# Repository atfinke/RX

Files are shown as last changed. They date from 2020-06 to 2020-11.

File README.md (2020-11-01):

# RX

A small stay at home side project. Bluetooth buttons that trigger actions on a Mac.
<br> <br><p align="center">
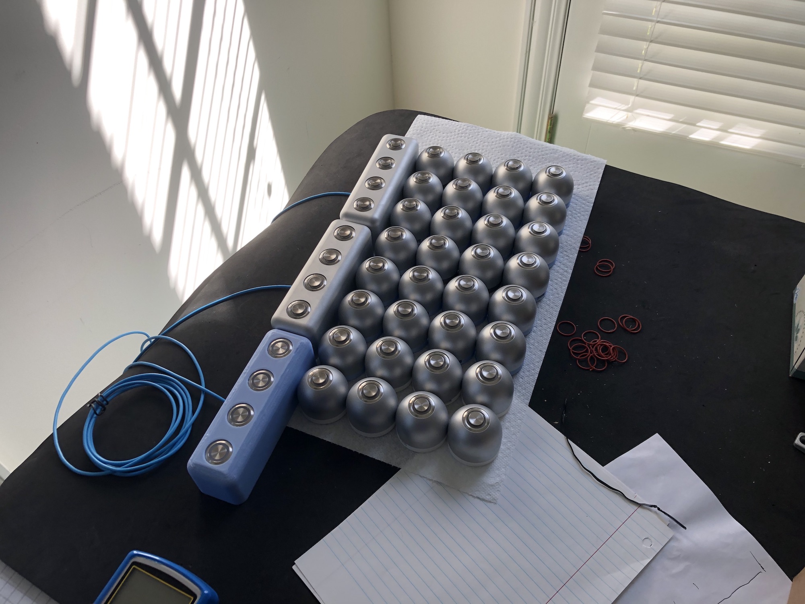
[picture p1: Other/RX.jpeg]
  
</p>

- R1 = V1: Bluetooth, USB Power
- R2 = V2: Bluetooth, Battery + Wireless Charging
- RM = Control theatre volume via Apple TV. Lights up when shaken to find in the dark.
- RD = Single button remote

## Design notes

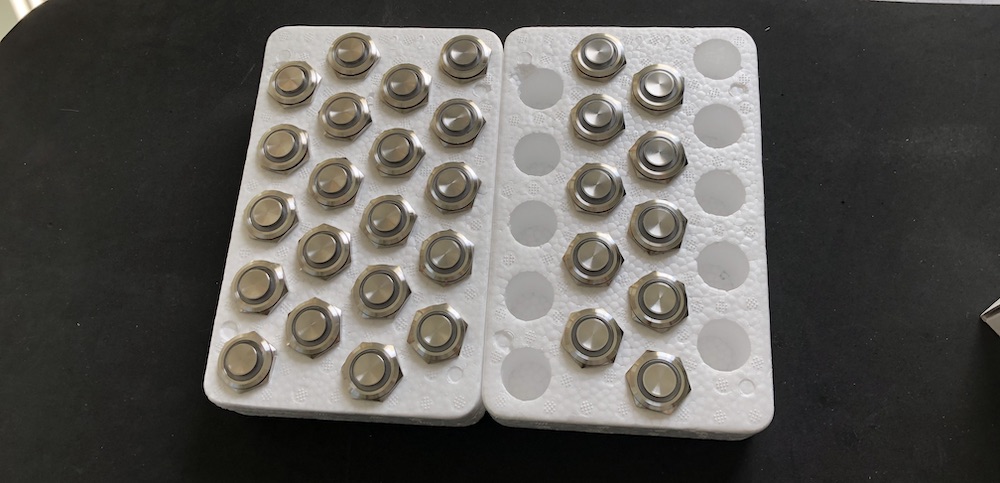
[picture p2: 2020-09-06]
RD/images/RD Buttons.jpg

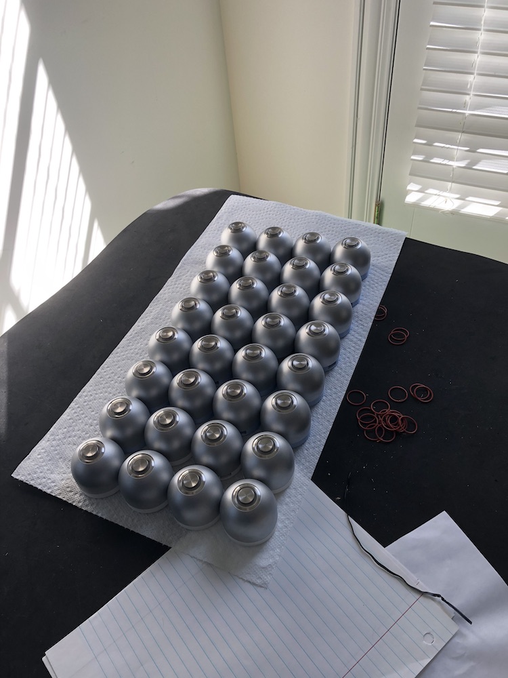
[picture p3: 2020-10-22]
RD/images/RD Complete.jpeg

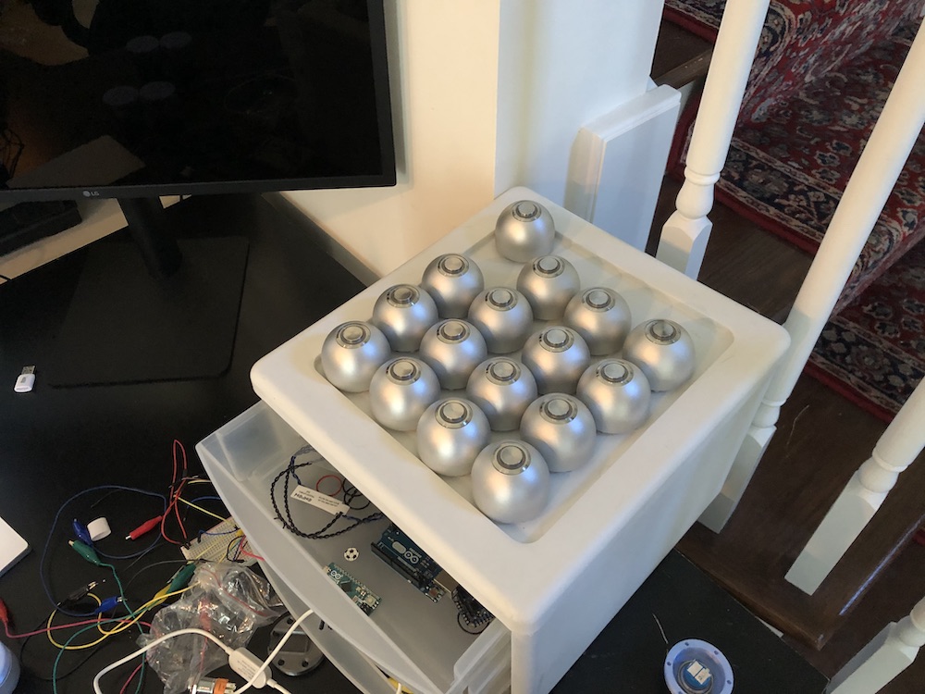
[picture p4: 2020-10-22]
RD/images/RD Without Base.jpeg

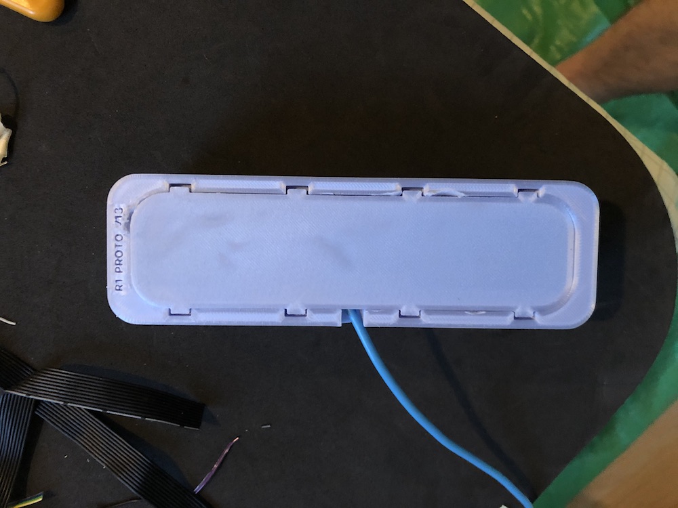
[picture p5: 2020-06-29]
R1/images/Proto V13 Bottom.jpeg

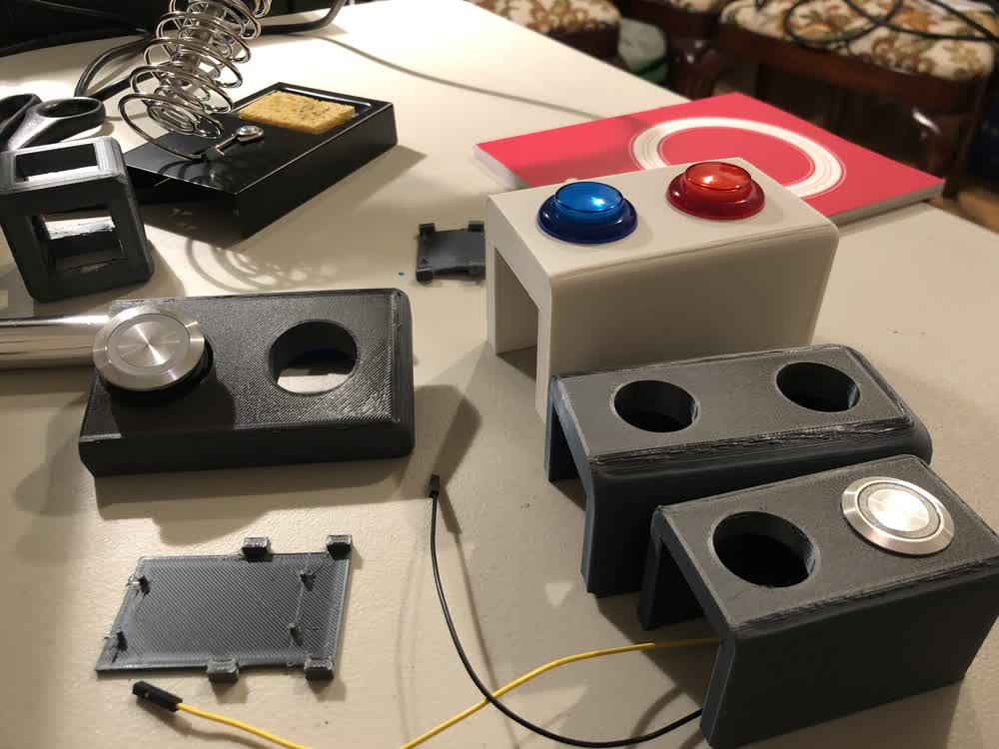
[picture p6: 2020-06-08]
R1/images/Proto V0 - V3.jpeg

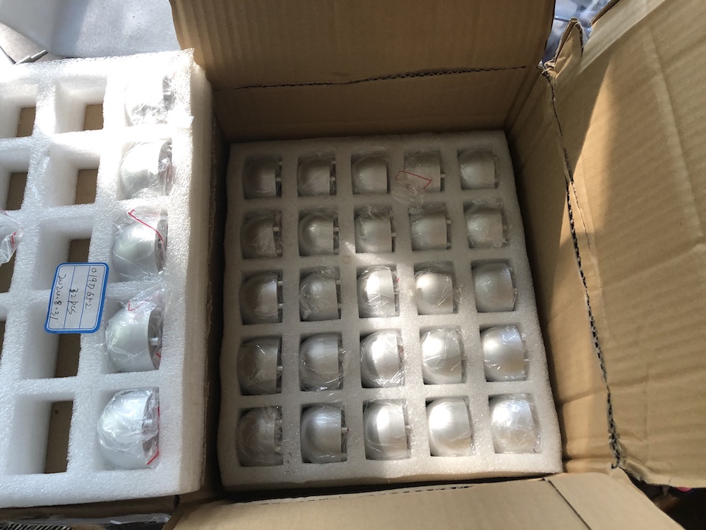
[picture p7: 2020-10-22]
RD/images/RD Enclosures.jpeg

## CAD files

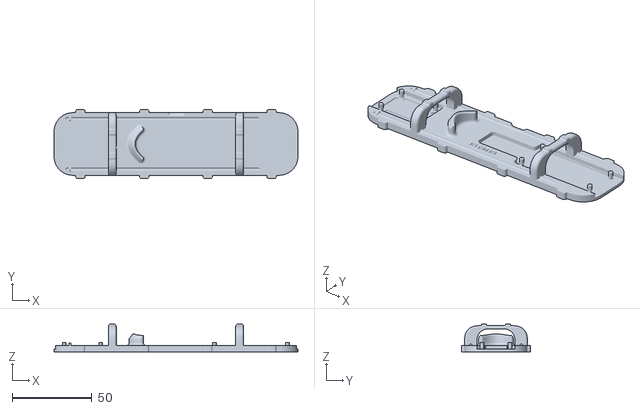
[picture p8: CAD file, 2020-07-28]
R1/cad/R1 RC B1.stl
153.2 x 43.4 x 17.4

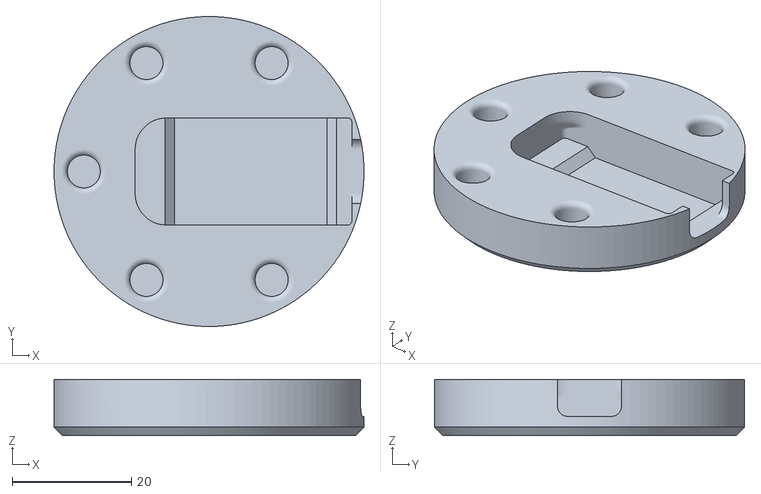
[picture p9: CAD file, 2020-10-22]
RD/cad/RD V17 B.stl
52.0 x 52.0 x 9.40

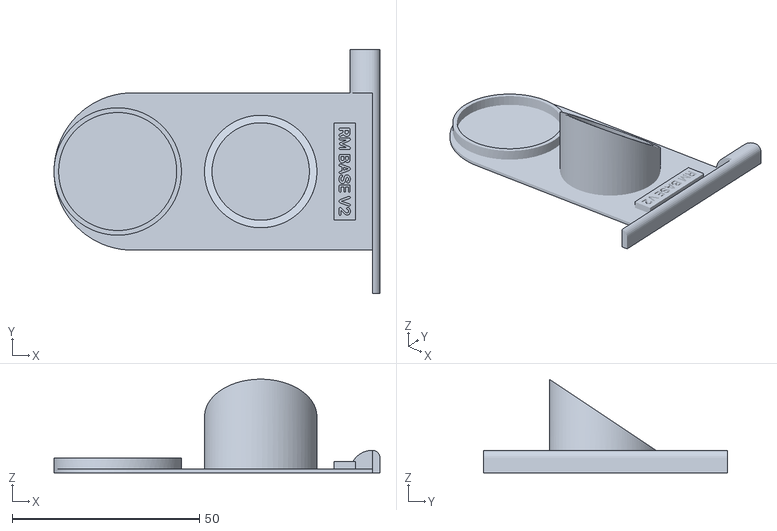
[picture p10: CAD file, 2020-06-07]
RM/cad/RM Base V2.stl
87.0 x 65.0 x 25.0

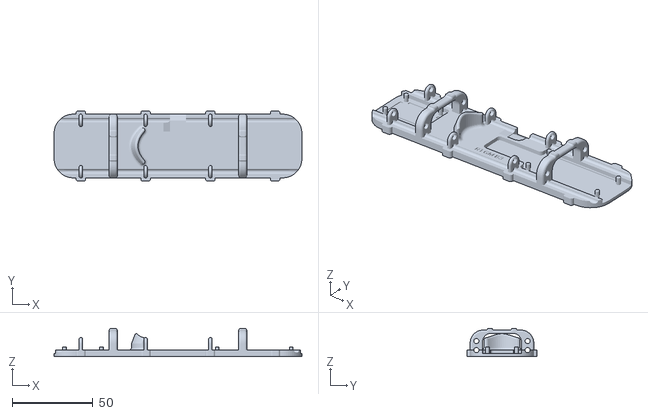
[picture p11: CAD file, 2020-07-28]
R1/cad/R1 RC B3.stl
153.2 x 43.4 x 17.4

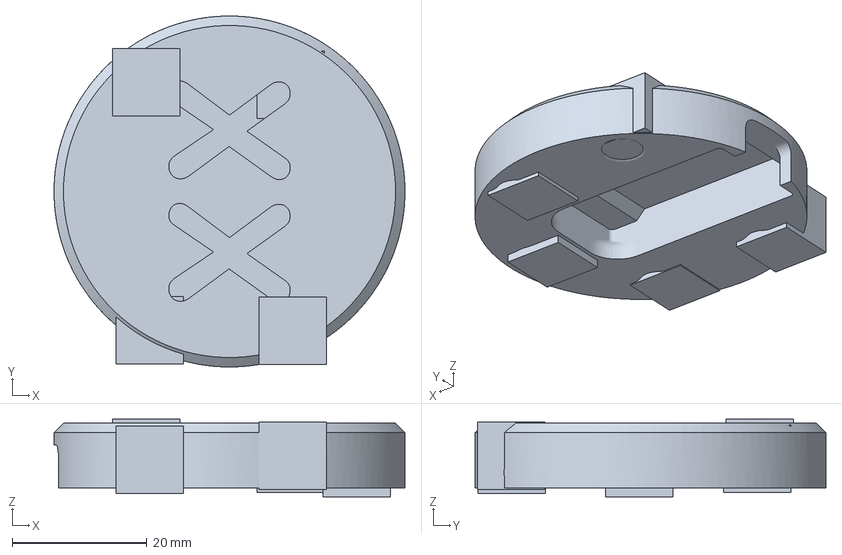
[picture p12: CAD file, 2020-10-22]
RD/cad/Cura Proj RD RC B.3mf
52.0 x 52.0 x 11.5 mm

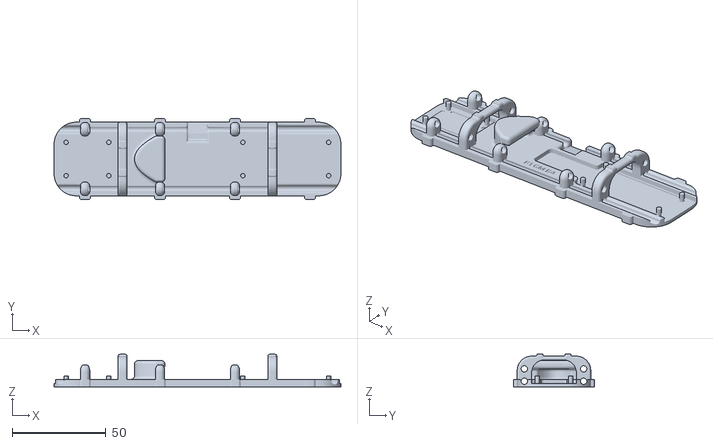
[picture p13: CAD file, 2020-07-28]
R1/cad/R1 RC B4.stl
153.2 x 43.4 x 17.4

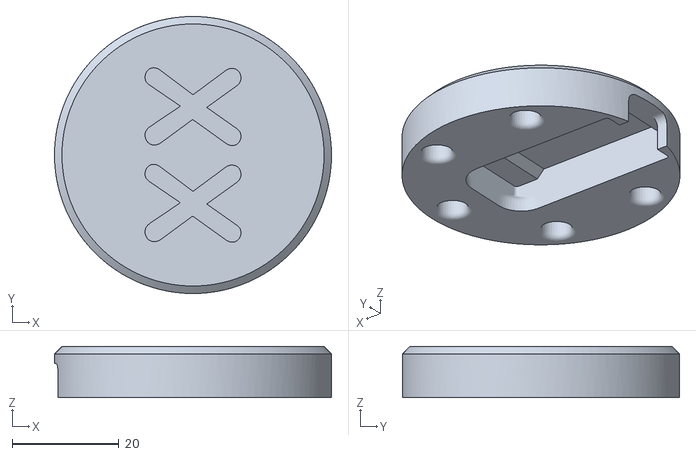
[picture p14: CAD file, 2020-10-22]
RD/cad/RD RC B.stl
52.0 x 52.0 x 9.60

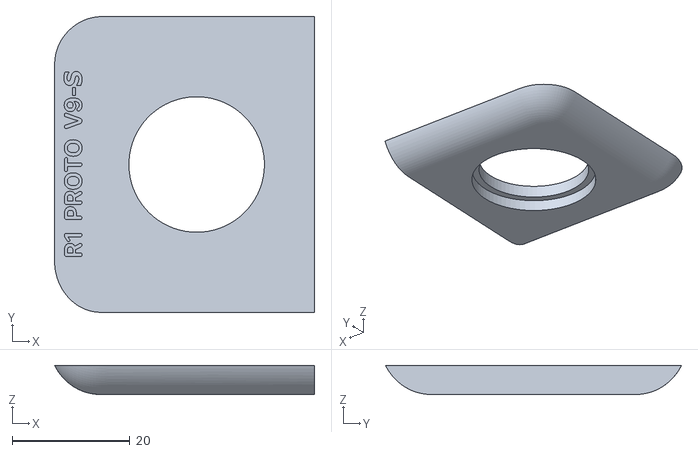
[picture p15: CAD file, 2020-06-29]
R1/cad/R1 Proto V9 - Fruit - No Support Test.stl
44.1 x 50.3 x 5.00

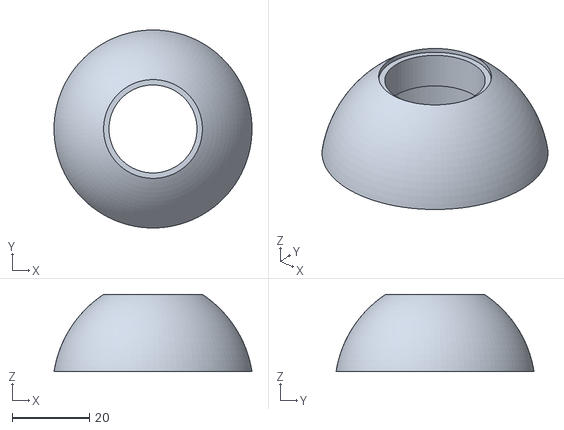
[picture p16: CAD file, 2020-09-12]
RD/cad/RD V8 T2.stl
51.3 x 51.3 x 20.0

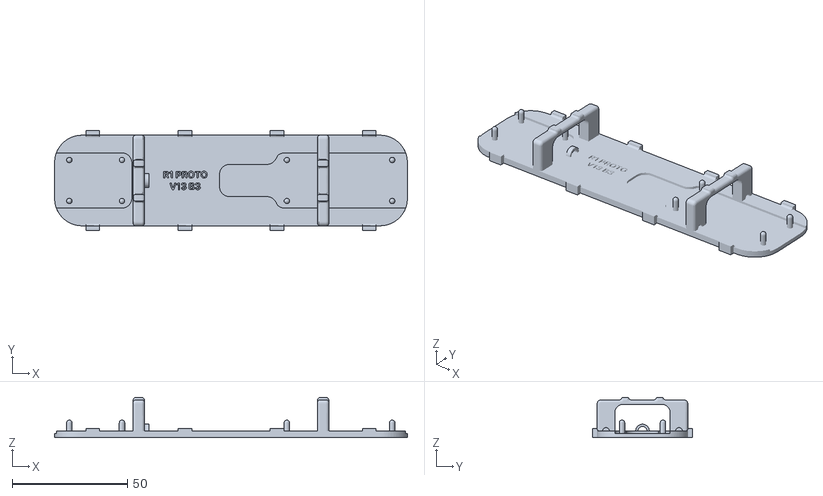
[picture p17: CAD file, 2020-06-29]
R1/cad/R1 Proto V13 B3.stl
153.2 x 43.4 x 17.4

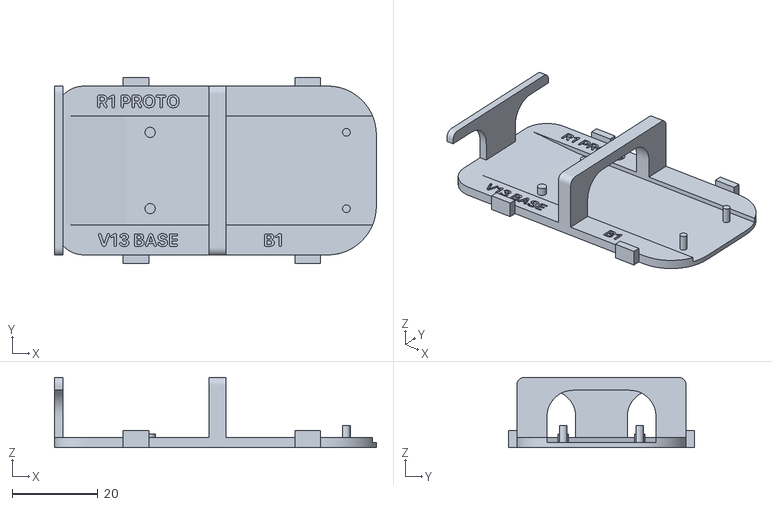
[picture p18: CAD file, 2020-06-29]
R1/cad/R1 Proto V13 B1.stl
75.0 x 43.4 x 16.4

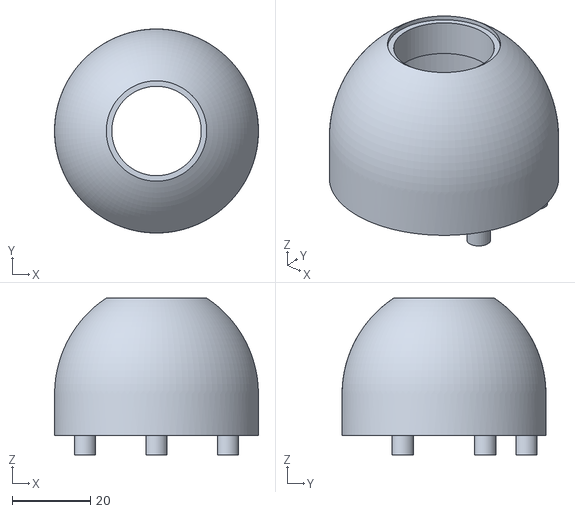
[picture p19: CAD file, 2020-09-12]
RD/cad/RD RC T.stl
52.0 x 52.0 x 40.0

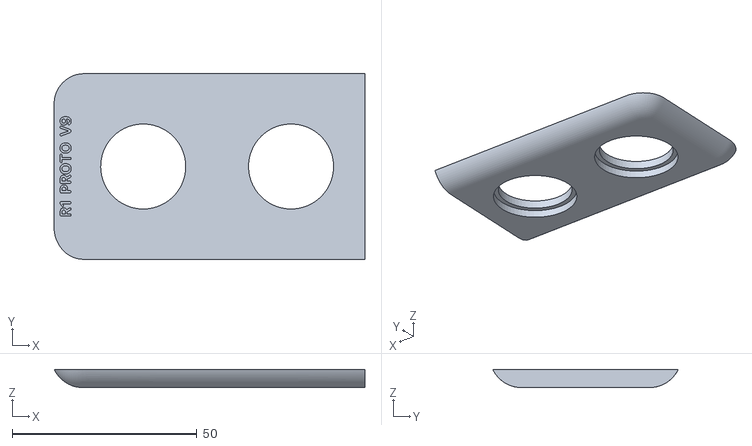
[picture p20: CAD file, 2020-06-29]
R1/cad/R1 Proto V9 - Fruit.stl
84.1 x 50.3 x 5.00

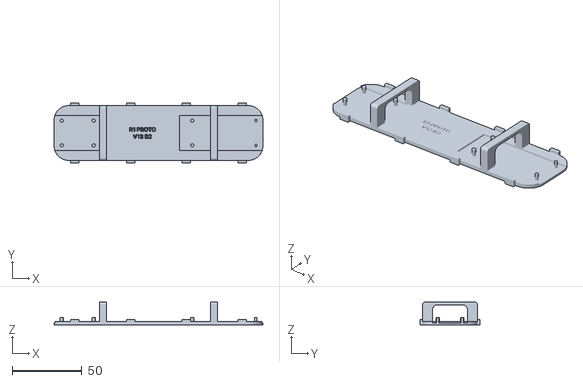
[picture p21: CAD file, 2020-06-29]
R1/cad/R1 Proto V13 B2.stl
150.0 x 43.4 x 16.4

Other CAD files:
R1/cad/R1 RC B2.stl
R1/cad/R1 RC B5.stl
R1/cad/R1 Proto V13 B4.stl
RD/cad/RD V8 T.stl
R1/cad/R1 Proto V1.ipt
R1/cad/R1 Proto V10 B1.ipt
R1/cad/R1 Proto V10 B2.ipt
R1/cad/R1 Proto V10 B2.stl
R1/cad/R1 Proto V10 B3.ipt
R1/cad/R1 Proto V10 B3.stl
R1/cad/R1 Proto V10 B4.ipt
R1/cad/R1 Proto V10 B4.stl
R1/cad/R1 Proto V10 B5.ipt
R1/cad/R1 Proto V10.ipt
R1/cad/R1 Proto V10.stl
R1/cad/R1 Proto V11.ipt
R1/cad/R1 Proto V11.stl
R1/cad/R1 Proto V12.ipt
R1/cad/R1 Proto V12.stl
R1/cad/R1 Proto V13 B1 - dim.ipt
R1/cad/R1 Proto V13 B2.ipt
R1/cad/R1 Proto V13 B3.ipt
R1/cad/R1 Proto V13 B4.ipt
R1/cad/R1 Proto V13.ipt
R1/cad/R1 Proto V13.stl
R1/cad/R1 Proto V13m.ipt
R1/cad/R1 Proto V14.ipt
R1/cad/R1 Proto V2 Base.ipt
R1/cad/R1 Proto V2.ipt
R1/cad/R1 Proto V3.ipt
R1/cad/R1 Proto V3.stl
R1/cad/R1 Proto V4.ipt
R1/cad/R1 Proto V4.stl
R1/cad/R1 Proto V5.ipt
R1/cad/R1 Proto V5.stl
R1/cad/R1 Proto V6.ipt
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

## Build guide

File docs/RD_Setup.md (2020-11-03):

# Hello!

When my plans for traveling and adventures after graduation were put on indefinite hold, I found myself with a bunch of extra time for [projects at home](https://github.com/atfinke/Stay-at-Home-Thoughts). One of those projects was the device you have in front of you now, RD.

RD is a tiny single button Bluetooth remote that can trigger actions based on the app you are using on your Mac.

# Setup

1. [Handling RD](#Handling-RD)
2. [Powering RD](#Powering-RD)
3. [Connecting to RD](#Connecting-to-RD)

## Handling RD
Hopefully you  made it this far without accidentally throwing your RD out a window. The top enclosure is only secured to the base by friction, which makes the device easier to disassemble. This also means I do not recommend holding the device upside down. On the base of the device is its serial number, a two character string.

## Powering RD
While this is a Bluetooth device, it uses Micro-USB for power because I did not feel comfortable shipping lithium-ion packs across the country. If you feel skilled with a soldering iron and want to add a permanent battery to your device, the circuit board does feature a battery input pin.

To turn RD on, grab a Micro-USB cable and plug it into a spare USB brick. While I recommend the USB brick approach, you can also directly connect RD to your Mac via cable. Powering RD from your Mac will cause it to appear as a flash drive in Finder. When prompted to set up RD as a keyboard, just close the window.

A few seconds after connecting RD to power, it should turn blue, indicating that it is ready to connect to your Mac. Note that if you put your Mac to sleep, while the RD light will turn off, RD itself is still on. When you use your Mac again, it will automatically reconnect. You should never need to unplug or reboot RD.

## Connecting to RD
Grab your Mac, we are almost done. First, download (or compile for yourself) the RX Preferences app and the RXd app from the releases section in the RX repo [here](https://github.com/atfinke/RX/releases).

Then, after turning RD on, open the RX Preferences app, and it should automatically find your device nearby.

Now you can start configuring the device for each of your apps! Press the + button to select an app. Whenever your Mac's frontmost app is the one you select, RD will configure itself based on the preferences you set next. You can click the color well circles to specify the color of the light in the specified state. Next, the fun part, click the “Select Action” button and select an *AppleScript* .scpt file to run when you press RD. Woah, AppleScript…

Yeah, AppleScript! AppleScript is perfect for this use case for a number of reasons. Here are just a few: 

- First, AppleScript can perform powerful system actions, like programmatic [key input events](https://apple.stackexchange.com/questions/36943/how-do-i-automate-a-key-press-in-applescript). 

- Secondly, AppleScript is one of the easiest ways to script apps interactions. Many apps provide native bridges to AppleScript and there are tons of resources available online to learn more. Additionally, in `Script Editor.app`, navigating to `File->Open Dictionary` will show you the available AppleScript dictionaries for the apps installed on your Mac. 

- Finally, running shell scripts from AppleScript is easy with [‘do shell script’](https://developer.apple.com/library/archive/technotes/tn2065/_index.html). This means that if AppleScript is not your thing, you can write your actions in Python, Swift, almost anything you can run from the command line! I generally write my actions entirely in AppleScript or by calling out to a Python script. 

You can see some sample workflows in the RX repo example actions folder [here](https://github.com/atfinke/RX/tree/main/Shared/Actions). If you are looking for a quick hello world alert script to test out your RD, I recommend the one in the RX repo [here](https://github.com/atfinke/RX/blob/main/Shared/Actions/System/Hello%20World.scpt).

The last piece of the puzzle is the RXd app, which is essentially a wannabe daemon process (the RXd app has no interface and will not appear in your dock). Its function is to act as the bridge between your Mac and RD. 

After setting up your device in the RX Preferences app for the first time, launch RXd. RXd should automatically connect to RD and if you enable its notifications, will alert you once connected. I recommend adding the RXd app as a login item (System Preferences -> Users & Groups), which means the app will start whenever you log in. The RXd app is always up to date with changes you make in the RX Preferences app.

Congrats! You are all set up and ready to go! Feel free to stop reading here if you are not interested in learning more about how the device is made or ways to further customize the hardware.

# How It’s Made

RD started as a project to use up all the extra parts I had from my previous project, R1, but I decided to expand the scope a bit after some folks responded well to the first few prototypes. Planning for the first and only batch of 32 RDs started in early August 2020 and assembly was finished by mid September.

To create the CAD files, I used [Autodesk Inventor](https://www.autodesk.com/products/inventor/). You can find all the CAD files (+ most of the iterations) in the RX repo [here](https://github.com/atfinke/RX/tree/main/RD/cad).

The top of the enclosure is [6061-T6 aluminum](https://en.wikipedia.org/wiki/6061_aluminium_alloy#6061-T6) with a bead blast finish and was manufactured by [Shenzhen Kingsun Enterprises Co., Ltd.](https://www.kingsun1.com) (via [Xometry](https://www.xometry.com)).

The bottom is PLA plastic, 3D printed with a [Creality Ender 5](https://www.creality.com/goods-detail/ender-5-3d-printer) using [Cura](https://ultimaker.com/software/ultimaker-cura) to convert the CAD files into g-code instructions. The serial number font is SF Pro Rounded. Each takes about three hours to print with a 10% fill density.

Inside RD is an [ItsyBitsy nRF52840 board](https://www.adafruit.com/product/4481), which is a development board with the [nRF52840](https://www.nordicsemi.com/Products/Low-power-short-range-wireless/nRF52840) chip. This chip is powerful enough to run a fork of python called [CircuitPython](https://circuitpython.org) (it can also be modified to work with the [Arduino IDE](https://www.arduino.cc/en/main/software)). If you connect RD to your Mac via a USB cable, it will appear as a flash drive. On boot, it runs the code in `main.py`. It’s your chip now, so feel free to customize it anyway you like! `hardware_config.py` is unique to your device, so I recommend creating a copy of that before doing anything too crazy. The rest of the files can be restored from the microcontroller directory in the RX repo [here](https://github.com/atfinke/RX/tree/main/Shared/Microcontroller). 

The actual button is a custom sku manufactured by [Lanboo](https://www.lanbooswitch.com), which I first used for R1. You can read a bit about my multi-month long international button search [here](https://github.com/atfinke/Stay-at-Home-Thoughts#may). The button is a high head (the top sticks out) momentary (it doesn’t lock in place when pressed) 22mm diameter button with a built in resistor. There is also a red, green, and blue led inside. To show a color like white, all three leds illuminate at the same time. This is why some colors may have non-uniform illumination. 

Final assembly took about an hour per RD. I used a 30W soldering iron with [60/40 lead rosin-core solder](https://www.adafruit.com/product/145) for the internal connections, which I then tested using a [model 9205B multimeter](https://www.digikey.com/product-detail/en/adafruit-industries-llc/2034/1528-2034AD-ND/12084169). Finally, I configured the bootloader, uploaded the software, and ran a debug mode for a last check.

On the Mac side, the RXd app uses public [Foundation APIs](https://developer.apple.com/documentation/appkit/nsworkspace/1535049-didactivateapplicationnotificati) to detect active app changes and Core Bluetooth to communicate with RD. To trigger your actions, RXd launches [osascript](https://ss64.com/osx/osascript.html) via an [NSTask](https://developer.apple.com/documentation/foundation/nstask), passing the url to a cached copy of your selected script. You can click the script name in the RX Preferences app to show its location in Finder.

—

That’s about it! Hope you enjoy and let me know if you run into any issues.
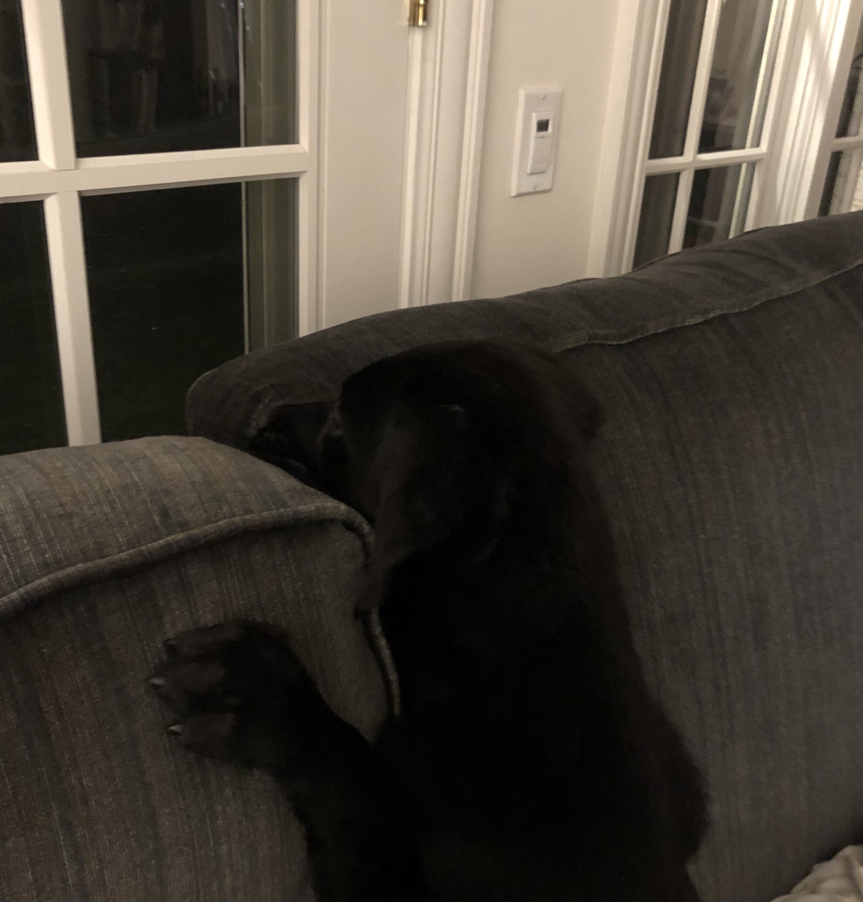
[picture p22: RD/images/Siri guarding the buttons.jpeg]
<br><br><br><b>My mom's puppy, "Siri", protecting the completed RDs<b>

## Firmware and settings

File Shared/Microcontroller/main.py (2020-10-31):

import board
import neopixel
import supervisor
import time

from debug_mode import DebugMode

from bluetooth import Bluetooth
from lights import Lights
from buttons import Buttons

from constants import Constants
from hardware_config import HardwareConfig
from helpers import hex_to_rgb, num_array_from_buffer, color_array, single_color_array, color_array

class Main:

    def __init__(self, force_debug=False):
        print("__init__")

        # Setup board led (R1 only)
        self.internal_led = None
        if HardwareConfig.INTERNAL_LED is not None:
            self.internal_led = neopixel.NeoPixel(HardwareConfig.INTERNAL_LED, 1)

        self._update_internal_led_color((255, 0, 0))

        self.buttons = Buttons(HardwareConfig.BUTTON_INPUTS)
        self.buttons_count = len(HardwareConfig.BUTTON_INPUTS)

        # Check if should enter debug hardware mode
        time.sleep(0.5)
        _, states = self.buttons.states()
        self._last_button_states = states
        if states[:1] == [True] or force_debug:
            DebugMode(self.buttons)

        # Init the lights, set to blue
        self.lights = Lights()

        self.lights.start_transition_to_new_resting_colors(color_array([0, 0, HardwareConfig.MAX_LED_VALUE], self.buttons_count))
        self.transition_start_time = time.monotonic_ns()
        while self.transition_start_time is not None:
            self.update_leds_for_transition()

        self._update_internal_led_color((0, 255, 0))

        # Prep the bluetooth vars
        self.buffered_colors = []
        self._update_internal_led_color((0, 0, 255))

        self.bluetooth = Bluetooth()
        self.bluetooth.connect()

        self.lights.start_transition_to_new_resting_colors(single_color_array(0, self.buttons_count))
        self.transition_start_time = time.monotonic_ns()

        print("connected")
        self._update_internal_led_color((0, 0, 0))

    def _update_internal_led_color(self, color):
        if self.internal_led is not None:
            self.internal_led[0] = color

    def run(self):
        while True:
            while self.bluetooth.is_connected():
                self.read_bluetooth_data()
                self.update_buttons()
                
                if self.transition_start_time:
                    self.update_leds_for_transition()
                else:
                    self.bluetooth.heartbeat()
                    time.sleep(0.05)

            print("not connected - waiting a bit for fast reconnect")
            self.bluetooth.connect(timeout=Constants.FAST_RECONNECT_WAIT_TIME_BEFORE_RESETING_LIGHTS)

            if self.bluetooth.is_connected():
                print("fast connect success")
                continue
            else:
                print("fast connect failed")
                
            self.lights.set_to_colors_tuple((0, 0, 0))
            self.bluetooth.connect()

    # BUTTONS

    def update_buttons(self):
        # adjusted_states = when a button is pressed, adjusted_states for button is only 'True' for first tick
        # states = truth
        adjusted_states, states = self.buttons.states()

        # Only R1
        if states[:4] == [True, True, True, True]:
            self._reset_bluetooth()
            return

        # Send button data (button num starts at 1)
        for (index, is_on) in enumerate(adjusted_states):
            if is_on:
                self.bluetooth.write("b:" + str(index + 1))
                self.lights.update_button_state(index, True)
            elif self._last_button_states[index] and not states[index]:
                self.lights.update_button_state(index, False)

        self._last_button_states = states

    def update_leds_for_transition(self):
        if not self.transition_start_time:
            return

        # Get percent progress
        time_since_start_ms = round((time.monotonic_ns() - self.transition_start_time) / 1e6, 1)
        progress = time_since_start_ms / Constants.LIGHT_TRANSITION_DURATION
        self.lights.update_transition_to_new_resting_colors_progress(progress)
        if progress >= 1:
            self.transition_start_time = None

    # BLUETOOTH

    def _reset_bluetooth(self):
        self.bluetooth.disconnect()
        self.lights.set_to_colors_tuple((0, 0, 0))
        self.transition_start_time = None
        self.buffered_colors = []
        self.bluetooth.connect()

    def clear_buffers(self):
        self.buffered_colors = []
        self.transition_start_time = None

    def read_bluetooth_data(self):
        data = self.bluetooth.read()

        if data is None or len(data) == 0:
            return

        if "q" in data:  # RXd says to disconnect
            self.clear_buffers()
            self._reset_bluetooth()
            return

        if "n" in data:  # RXd ready for name
            self.bluetooth.write("n:" + HardwareConfig.NAME)
            data = data.replace("n", "")

        if "s" in data:  # RXd sending new colors
            self.clear_buffers()
            data = data.split("s")[-1]  # throw away previous colors in data

        if len(data) == 0:
            return

        # Seperate colors
        hex_values = [data[i:i+6] for i in range(0, len(data), 6)]

        # Convert to rgb
        rgb_values = [hex_to_rgb(n) for n in hex_values]

        # Add to buffer (not all colors can fit in one message)
        self.buffered_colors += rgb_values

        # If we have gotten all colors needed...
        if len(self.buffered_colors) >= self.buttons_count * 2:
            resting_colors = num_array_from_buffer(buffer=self.buffered_colors, offset=0, light_count=self.buttons_count)
            self.lights.start_transition_to_new_resting_colors(resting_colors)

            pressed_colors = num_array_from_buffer(buffer=self.buffered_colors, offset=self.buttons_count, light_count=self.buttons_count)
            self.lights.update_pressed_colors(pressed_colors)
            self.transition_start_time = time.monotonic_ns()


print("Booted FW: {}".format(Constants.FW_VERSION))
supervisor.disable_autoreload() # to enable call enable_autoreload() once
main = Main(force_debug=False)
main.run()

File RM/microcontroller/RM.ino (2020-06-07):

#include "Adafruit_BluefruitLE_UART.h"
#include <Adafruit_CircuitPlayground.h>

// CONSTANTS

static const int VOLUME_UP_INPUT_PIN = 3;
static const int VOLUME_DOWN_INPUT_PIN = 2;

static const int VOLUME_UP_OUTPUT_PIN = 9;
static const int VOLUME_DOWN_OUTPUT_PIN = 6;

static const int ACCELEROMETER_MOVEMENT_TRIGGER_THRESHOLD = 110;
static const int ACCELEROMETER_MOVEMENT_MIN_TIME_SINCE_PRESS = 1000;
static const int ACCELEROMETER_LED_TIME = 2000;

static const int ACCELEROMETER_VOLUME_UP_LED_VALUE = 20;
static const int ACCELEROMETER_VOLUME_DOWN_LED_VALUE = 50;

static const int PRESSED_LED_VALUE = 255;

static const int STARTUP_LED_TIME = 10000;

static const bool INITIAL_SETUP = false;

// BUTTON STATE

int lastVolumeDownButtonValue = 0;
int lastVolumeUpButtonValue = 0;
int buttonValue = 0;
unsigned long pressedEndDate = 0;

// OTHER

unsigned long setupEndDate = 0;
unsigned long accelerometerEndDate = 0;
Adafruit_BluefruitLE_UART ble(Serial1, -1);

// SETUP

void setup(void)
{
  CircuitPlayground.begin();
  CircuitPlayground.setPixelColor(1, 0, 0, 20);

  if (!Serial) {
    delay(1000);
  }
  CircuitPlayground.setPixelColor(2, 0, 0, 20);

  if (Serial) {
    Serial.begin(115200);
  }
  CircuitPlayground.setPixelColor(3, 0, 0, 20);

  ble.begin(false);
  CircuitPlayground.setPixelColor(4, 0, 0, 20);

  ble.echo(false);
  CircuitPlayground.setPixelColor(5, 0, 0, 20);

  if (Serial) {
    ble.info();
  }
  CircuitPlayground.setPixelColor(6, 0, 0, 20);

  pinMode(VOLUME_DOWN_INPUT_PIN, INPUT_PULLUP);
  pinMode(VOLUME_UP_INPUT_PIN, INPUT_PULLUP);
  CircuitPlayground.setPixelColor(7, 0, 0, 20);

  pinMode(VOLUME_DOWN_OUTPUT_PIN, OUTPUT);
  pinMode(VOLUME_UP_OUTPUT_PIN, OUTPUT);
  CircuitPlayground.setPixelColor(8, 0, 0, 20);

  if (INITIAL_SETUP) {
    if (ble.factoryReset()) {
      Serial.println("success: factoryReset");
    } else {
      Serial.println("error: factoryReset");
    }

    if (ble.sendCommandCheckOK(F("AT+BleHIDEn=On"))) {
      Serial.println("success: hid");
    } else {
      Serial.println("error: hid");
    }

    if (ble.reset()) {
      Serial.println("success: reset");
    } else {
      Serial.println("error: reset");
    }

    if (ble.sendCommandCheckOK(F("AT+HWModeLED=disable"))) {
      Serial.println("success: led");
    } else {
      Serial.println("error: led");
    }

    if (ble.sendCommandCheckOK(F("AT+GAPDEVNAME=RM" ))) {
      Serial.println("success: name");
    } else {
      Serial.println("error: name");
    }
  }

  setupEndDate = millis();

}

// MAIN

void loop(void)
{
  checkStartup();
  checkAccelerometer();
  checkVolumeUpButton(true);
  checkVolumeUpButton(false);
}

// HELPERS

void checkStartup(void) {
  if (setupEndDate == 0) {
    return;
  }
  unsigned long duration = millis() - setupEndDate;
  if (duration > STARTUP_LED_TIME) {
    setupEndDate = 0;
    for (int i = 1; i < 9; i++) {
      CircuitPlayground.setPixelColor(i, 0, 0, 0);
    }
  }
}

void checkAccelerometer(void) {
  float motionX = CircuitPlayground.motionX();
  float motionY = CircuitPlayground.motionY();
  float motionZ = CircuitPlayground.motionZ();

  int composite = int(motionX * motionX + motionY * motionY + motionZ * motionZ);
  if (composite > ACCELEROMETER_MOVEMENT_TRIGGER_THRESHOLD) {
    if (pressedEndDate != 0) {
      if (millis() - pressedEndDate > ACCELEROMETER_MOVEMENT_MIN_TIME_SINCE_PRESS) {
        pressedEndDate = 0;
      } else {
        return;
      }
    }
    accelerometerEndDate = millis();
    analogWrite(VOLUME_UP_OUTPUT_PIN, ACCELEROMETER_VOLUME_UP_LED_VALUE);
    analogWrite(VOLUME_DOWN_OUTPUT_PIN, ACCELEROMETER_VOLUME_DOWN_LED_VALUE);
  } else if (accelerometerEndDate != 0) {
    unsigned long duration = millis() - accelerometerEndDate;
    if (duration > ACCELEROMETER_LED_TIME) {
      accelerometerEndDate = 0;
    }
  }
}

void checkVolumeUpButton(bool isVolumeUp) {
  int inputPin = isVolumeUp ? VOLUME_UP_INPUT_PIN : VOLUME_DOWN_INPUT_PIN;
  int outputPin = isVolumeUp ? VOLUME_UP_OUTPUT_PIN : VOLUME_DOWN_OUTPUT_PIN;
  int cpOutputPin = isVolumeUp ? 9 : 0;
  int& lastValueRef = isVolumeUp ? lastVolumeUpButtonValue : lastVolumeDownButtonValue;

  // check if button just pressed
  int buttonValue = (digitalRead(inputPin) - 1) * -1;
  if (buttonValue == 1 && lastValueRef == 0) {
    const char* command = isVolumeUp ? "+" : "-";
    String message = "AT+BLEHIDCONTROLKEY=VOLUME" + String(command);
    ble.println(message);
  }
  CircuitPlayground.setPixelColor(cpOutputPin, 0, 0, 20 * buttonValue);

  // 1) Turn button led on if pressed
  // 2) Turn button led off if not pressed and not shaking
  // 3) Turn button led to shaking value if not pressed and  shaking
  if (lastValueRef == 1) {
    analogWrite(outputPin, PRESSED_LED_VALUE);
    pressedEndDate = millis();
  } else if (accelerometerEndDate == 0) {
    analogWrite(outputPin, 0);
  } else {
    int value = isVolumeUp ? ACCELEROMETER_VOLUME_UP_LED_VALUE : ACCELEROMETER_VOLUME_DOWN_LED_VALUE;
    analogWrite(outputPin, value);
  }

  lastValueRef = buttonValue;
}

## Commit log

2020-06-08 variable button count
2020-07-28 R1 GM
    [R1 GM B1.ipt, R1 GM B1.stl, R1 GM B2.ipt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]
2020-09-12 RD Iteration
    [RD GM T.CATPart, RD GM T.ipt, RD GM T.stl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]
